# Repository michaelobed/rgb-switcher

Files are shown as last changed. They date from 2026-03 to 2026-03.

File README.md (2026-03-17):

# rgb-switcher

Render of v1.0 main board PCB

## What is it?

An open-source switcher for analogue RGBS and YPbPr video, so you don't have to.

## Why?

My wife and I are slowly amassing some retro gaming consoles which we quite enjoy, and needed a way to connect them all to a modern TV via a [gbs-control](https://github.com/ramapcsx2/gbs-control)-based line doubler. Unfortunately, most solutions for this either don't support RGBS, don't support YPbPr (a must for certain consoles), are SCART-only, don't have many inputs or are ludicrously expensive! Worst of all, they often don't feature remote control of any kind.

Soooo I did what any irritated engineer would do and made my own. 😂

## Overview

### Video switching

The rgb switcher is based around a very old Ben Heck design which uses [74CBT3244](https://www.ti.com/lit/ds/symlink/sn74cbt3244.pdf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) FET bus switches. The idea is simple: an [ATMEGA328PB](https://www.microchip.com/en-us/product/atmega328pb) microcontroller selects which of 8 of these bus switches should be active and switch their inputs through to some commonly connected outputs. The inputs consist of red, green, blue, sync, left audio and right audio. Since some of our consoles use YPbPr video, and because gbs-control-based line doublers have separate inputs for RGB(S) and YPbPr video, there are separate outputs for each, also selected with their own bus switch. A slide switch on the front of the PCB lets you select which video format each input uses, and therefore which output it should be routed to when selected. Bicolour LEDs also indicate which input is active and which format the video is in (red for RGBS, green for YPbPr).

I forgot to mention when writing this that the red, green and blue signals become Pr, Y and Pb respectively when an input is configured to be YPbPr instead of RGBS. There is no sync signal on the YPbPr output. 👍🏾

The input bus switches are selected using [74HC138](https://www.ti.com/product/CD74HC138) inverting line decoders. I could have just used pins on the microcontroller, but these lines go multiple places and I already use a hex inverter for something else on the board and didn't feel like having multiple!

I've used the same 9-pin mini-DIN connector that the Sega Mega Drive II uses, using the exact same pinout. One irritation that I discovered while deciding on this is that the cables I bought for testing (from AliExpress, admittedly) don't output the sync signal on pin 5, but instead output the composite video signal on pin 4! I've therefore added little switches to each input and to the RGBS output that let you choose pin 4 or 5 of the connector, and thus what you'd like to use as a sync signal. Be aware that there isn't any capacity to strip the sync signal from a composite video signal, both because I wasn't designing for that and because gbs-control does it already. If you like, you can add an [LM1881](https://www.ti.com/lit/ds/symlink/lm1881.pdf?ts=1737753066078&ref_url=https%253A%252F%252Fwww.google.com%252F) to the board if that's needed. This _doooes_ also imply that you could use this to switch composite video. Ha!

I got the cables I used for input/output from AliExpress, for example [this one](https://www.aliexpress.com/item/1005005996147435.html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), but the cables typically look like this:

What an I/O cable looks like

You can obtain these by searching for "sega mega drive 2 av cable" and you'll usually find one. You can then put [generic RCA couplers](https://www.aliexpress.com/item/32996572551.html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) on them to turn them into input cables.

### RGB LEDs

I also wanted the consoles to look nice on shelves or some sort of storage system we haven't decided on yet, so why not have the select lines also illuminate strips of 12V RGB LEDs? 🤣
I added some [IRF540](https://www.vishay.com/docs/91021/irf540.pdf) power MOSFETs to help with this. MOSFETs because efficient, power because current through the LEDs does add up!

Since I wanted to make this modular, the LED board now gets its own board as of v1.0 of the project:

Render of v1.0 LED board PCB

The LEDs also fade in/out when changing inputs. Yey! ^-^

### UART

Initially, I was going to build into the board a radio transceiver and build a separate board to use as a remote, partly because it's better than IR and because I had some nRF24L01 modules in my parts bin not really doing anything! It turns out that I hate them, powering them is finicky and I don't want to use an Arduino library, so I provided a generic UART interface instead. That way, I can design a remote of some kind in future (or maybe you, most esteemed reader, are the solution! 😉). I've also left a 5V power output near the UART connector so external remote interfaces can be powered.

I've left some brief documentation in the firmware README. The rgb switcher sends strings whenever the prev/next buttons are pressed and responds to external commands given using simple strings. You can even change the colour associated with an input this way!

Be warned, though, that there is no string sanitisation of any kind, so you can probably crash the microcontroller by being a silly billy with what you send it.

### Power

Finally, there's the power input. Anything that supplies 12V at ≥3A is fine, the high current being to drive the LEDs. Be sure to use a **centre-positive** DC barrel jack with a 5.5mm outer diameter and a 2.5mm inner diameter. I haven't provided any reverse voltage protection because I genuinely forgot. ~~Perhaps a Schottky diode in series with the 12V rail will do the trick.~~

## Final notes

I'm not an expert PCB designer, and this is my first time doing anything with video, but I managed to succesfully test this and get it working! I did make a hilarious number of really dumb mistakes which you can read in the changelog in the hardware README (yes I did eventually rewire the 9-pin mini-DINs by hand to test them). Despite all this, video and audio quality should be good.

If you like this design, you're welcome (and encouraged!) to fork this repo and make one yourself, modify it, sell it, I don't mind!

Happy gaming!

## In future

These are things I should probably have done but haven't had the time to do yet:

- ~~**Make the board smaller**! It would probably have been better to make the switcher with an "LED board" as a module that communicates over the UART, SPI, I2C, etc. Most importantly, it brings cost down further to not make such a large 4-layer PCB, especially if you're not interested in the RGB LED bit.~~
- **Create a reference design for a remote board** that lets you use one of those universal IR TV remotes with it, or maybe even learn codes from an existing IR remote.
- **Create an enclosure**. I'm a CAD noob but it shouldn't be too hard. It could even just be an identically-shaped PCB with some elaborate artwork on it!
- **Give the LED board reverse voltage protection**. This is particularly important for the +12V rail as there's currently nothing stopping a centre-negative DC connection from frying everything. While I suggested a Schottky diode earlier, I'm thinking a P-channel power MOFSET, for voltage drop and power dissipation reasons.

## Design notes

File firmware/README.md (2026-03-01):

# rgb switcher firmware

This firmware was written for the Microchip ATMEGA328PB. It was initially tested on an ATMEGA328P, which should be pin-compatible. Actually, with a little bit of work, this will probably run on anything, so use anything you like if the world one day runs out of those.

## How to build

You will need:
- A text editor. I use [Visual Studio Code](https://code.visualstudio.com) and have added a `.vscode` folder to the repo.
- The AVR GCC toolchain. How you get this depends on your OS, but if you're on macOS like me, I recommend [this repo](https://github.com/osx-cross/homebrew-avr) which contains a guide using a Homebrew-based approach.
- AVRDude. As with AVR GCC, you will need to get this according to your OS's method of doing that. If you've installed Arduino, you likely already have it. If you're on macOS and used the guide from earlier, you can install it by typing `brew install avrdude` in Terminal.

If you happen to be on an arm64 Mac, you should now be able to do either of the following:
- Open `firmware/main_board/src` in Visual Studio code, then run the _Build (Mac)_ task.
- In Terminal, do `cd firmware/main_board` then `../scripts/build_mac.sh`, which achieves the same thing.

This will build a .hex file to `firmware/main_board/bin`, which you can now flash using AVRDude.

If you're not using an arm64 Mac, you will need to change some directories in the `build_mac.sh` script, or create an equivalent for your platform. If you do happen to be on a Windows machine, please feel free to contribute a batch script or equivalent to the repo!

## UART protocol

The UART can receive commands from other devices and respond to them with an acknowledgement. This is useful both for remotely controlling the rgb switcher and for connected devices finding out its latest state (e.g. if the prev/next buttons are pressed). A command-response system has been implemented for controlling the rgb switcher and uses human-readable ASCII characters for everything.

The UART is configured as 8N1, running at 38400 kbaud.

The list of currently available commands is given below:

| Command | Format | Description |
| --- | --- | --- |
| Previous input | `p` | Decrements currently selected input. |
| Next input | `n` | Increments currently selected input. |
| Switch to input | `sN` | Switches to input `N`. |
| No input | `o` | Deselects all inputs. |
| Change input colour | `cNRRGGBB` | Changes the RGB LED colour associated with input `N` to the colour `RRGGBB`, where `RR`, `GG` and `BB` are 8-bit hexadecimal numbers representing the red, green and blue values of the colour. |
| Acknowledgement | `aCP` | Acknowledgement of the command `C` and its parameters `P`. `P` can be any length depending on the command being acknowledged. |
| Hello | `h` | Currently unused, but could be used to detect the presence of other devices. |
| Firmware version | `v` | Queries the switcher for its current version, given as an ASCII string of up to 16 characters. |

All strings sent or received are required to end in a newline (`\n`) character. Windows style `\r\n` endings are fine as the `\r` will just be ignored. As mentioned in the main README, no string sanitisation is performed, and no bounds checking either, so if you supply a malformed string or pass in an out-of-bounds input index...well I'm sure you can handle it! 😅

Feel free to extend this and make cool remotes and interfaces and things!

## EEPROM memory map

| Range | Description |
| --- | --- |
| 0x0000 - 0x000f | No man's land! It's apparently unreliable, so avoid. |
| 0x0010 - 0x0013 | Signature, known value used to verify that data exists. |
| 0x0020 - 0x003f | RGB LED colour data for each input (4 bytes * 8). |

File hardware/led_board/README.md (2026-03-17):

# rgb switcher led board

Here's the KiCad design file for the LED board. As before, third-party libraries are included where necessary, and there's an included BOM in the [KiCAD JLCPCB tools](https://github.com/bouni/kicad-jlcpcb-tools) format.

Bear in mind that you don't absolutely have to use the parts referenced in there if they aren't in stock on LCSC, or if you can source them from elsewhere, or if better/cheaper alternatives will work.

FWIW, here are some alternative links to things you will need. I used AliExpress myself, but these should be equivalent:

- [RGB LED connectors](https://uk.farnell.com/amphenol-anytek/oq04125100j0g/terminal-block-r-a-header-4way/dp/3810285) (Farnell)
- [+5v in/out connector](https://uk.farnell.com/camdenboss/ctb932hd-2/terminal-block-header-2pos-th/dp/2493677) (Farnell)
- [On/off switch](https://www.digikey.co.uk/en/products/detail/e-switch/100SP3T2B4M6RE/378850) (DigiKey)

## changelog

### v1.0

- initial version, based on v0.2 main board design.
- eliminated line decoder and NOT gate so power mosfets are driven directly by mcu gpio.

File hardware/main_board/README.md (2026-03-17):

# rgb switcher main board

Here's the KiCad design file for the main board. I've included all required libraries as a lot of the components I had to find or make from scratch. I've also included a bill of materials (BOM) for reference, which you will need the rather excellent [KiCAD JLCPCB tools](https://github.com/bouni/kicad-jlcpcb-tools) plugin to use. I've done this so that JLCPCB-compatible BOM and CPL files can be directly exported without fuss.

Bear in mind that you don't absolutely have to use the parts referenced in there if they aren't in stock on LCSC, or if you can source them from elsewhere, or if better/cheaper alternatives will work.

FWIW, here are some alternative links to things you will need. I used AliExpress myself, but these should be equivalent:

- [Output indicator LEDs](https://uk.farnell.com/multicomp-pro/mcl056purgw/led-5mm-ac-hi-red-grn/dp/1581207) (Farnell)
- [+5v in/out connector](https://uk.farnell.com/camdenboss/ctb932hd-2/terminal-block-header-2pos-th/dp/2493677) (Farnell)
- [Video input/output connectors](https://www.digikey.co.uk/en/products/detail/kycon-inc/KMDGX-9S-BS-1/10127398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) (DigiKey)

## changelog

### v0.1

- initial version. mistakes were made. 🥲

### v0.2

- corrected reversed pinout of icsp connector.
- corrected reversed pinout of uart connector.
- corrected orientation of prev/next buttons.
- corrected "output on" leds so rgb is red and ypbpr is green.
- corrected stupid pin numbering of mini-din footprint.
- added holes to 9-pin mini-din footprint to prevent ripping connector off board during disconnection.
- moved rgb/ypbpr switches closer to edge for ease of use.
- reduced brightness of "output on" leds.
- permitted switching between pins 4 and 5 of the input/output connectors to support using non-rgbs cables.
- connected PIN_SELEN net to front LED line decoders to allow them to be switched off.

### v1.0

- removed led functionality so it functions only as a video switcher.
- reduced the board dimensions to 135x226mm.
- moved prev/next buttons closer to edge for ease of use.
- migrated bom to [KiCAD JLCPCB tools](https://github.com/bouni/kicad-jlcpcb-tools) plugin format for ease of exporting bom and cpl files.
- lots of routing improvements

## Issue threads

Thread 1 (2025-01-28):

Audio can still distort!

michaelobed, 2025-01-28:
While testing this with a PlayStation 2 playing FIFA Street going through the YPbPr output (a game I deliberately chose because the audio can get loud), I've found the audio still clips. This might be because of the biasing circuit, but I'm not sure.

I've now got some investigative work to do to find out whether the biasing circuitry is even necessary. If the distortion goes away without it, I'll remove it.

If it turns out that removing the biasing circuitry breaks audio, I could simply reduce the gain of the op-amps slightly.

michaelobed, 2025-02-04:
I've done a bit of investigation, and it seems that removing the biasing circuitry seriously breaks audio. In the best case, audio is very distorted and crackly, and in the worst case I get almost no audio, with the occasional crackle making its way through. After biasing the signal, the bus switches will pass audio through cleanly and without issues.

Based on these findings then, I'll play with adding a TL-074-based amplifier at the output with the gain set to <1 to act as attenuation.

michaelobed, 2025-02-06:
I'll need to measure a few things to get an idea of gain, following my comment about how much louder the output is than the input.

Here I've fed a 1kHz sine wave into an input (yellow) and measured the output (blue). This was as high as I could turn up the input before the output became very nonlinear:

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

Past ~900mV pk the output signal experiences nonlinearities.

michaelobed, 2025-02-17:
Attempting to power the op-amps off of 12V was unsuccessful. It's just as distorted as before. I suspect it's because the audio signal is still hitting the 0V rail when biased up to +2V5.

What _was_ successful, though, was removing the biasing circuitry entirely. 😒
I'm annoyed about this because I was convinced that negative voltages would be a problem for the bus switches, but evidently not. I think I'm just going to make that change to the schematic and be done with this. 😂

Closed 2025-02-17.

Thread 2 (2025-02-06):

Add standby feature

michaelobed, 2025-02-06:
It may be desirable to keep the RGB switcher on but not have any outputs enabled. The firmware actually used to work this way, but the way the front LED logic was implemented currently makes it impossible to turn the LEDs off without hardware changes.

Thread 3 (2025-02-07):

Actually remember what the colours were set to

michaelobed, 2025-02-07:
I added code to let people change what RGB LED colour each input is, but no way to remember them! I'm annoyed I over looked it, but it's time to use the AVR EEPROM!

michaelobed, 2025-02-07:
Done! Praise God! 🙌🏾

Closed 2025-02-07.

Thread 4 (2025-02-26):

Change to MIT license

michaelobed, 2025-02-26:
I've not actually open-sourced a project before, but I've realised how restrictive the GNU GPL license can be, in that any derivative but proprietary works must disclose source code.

I've said in the README that I encouraged doing literally whatever one wants with the firmware and hardware designs, and I meant it, so I've created this issue to formally state that I'm switching this repo over to the MIT license, which will allow that.

Closed 2025-02-26.

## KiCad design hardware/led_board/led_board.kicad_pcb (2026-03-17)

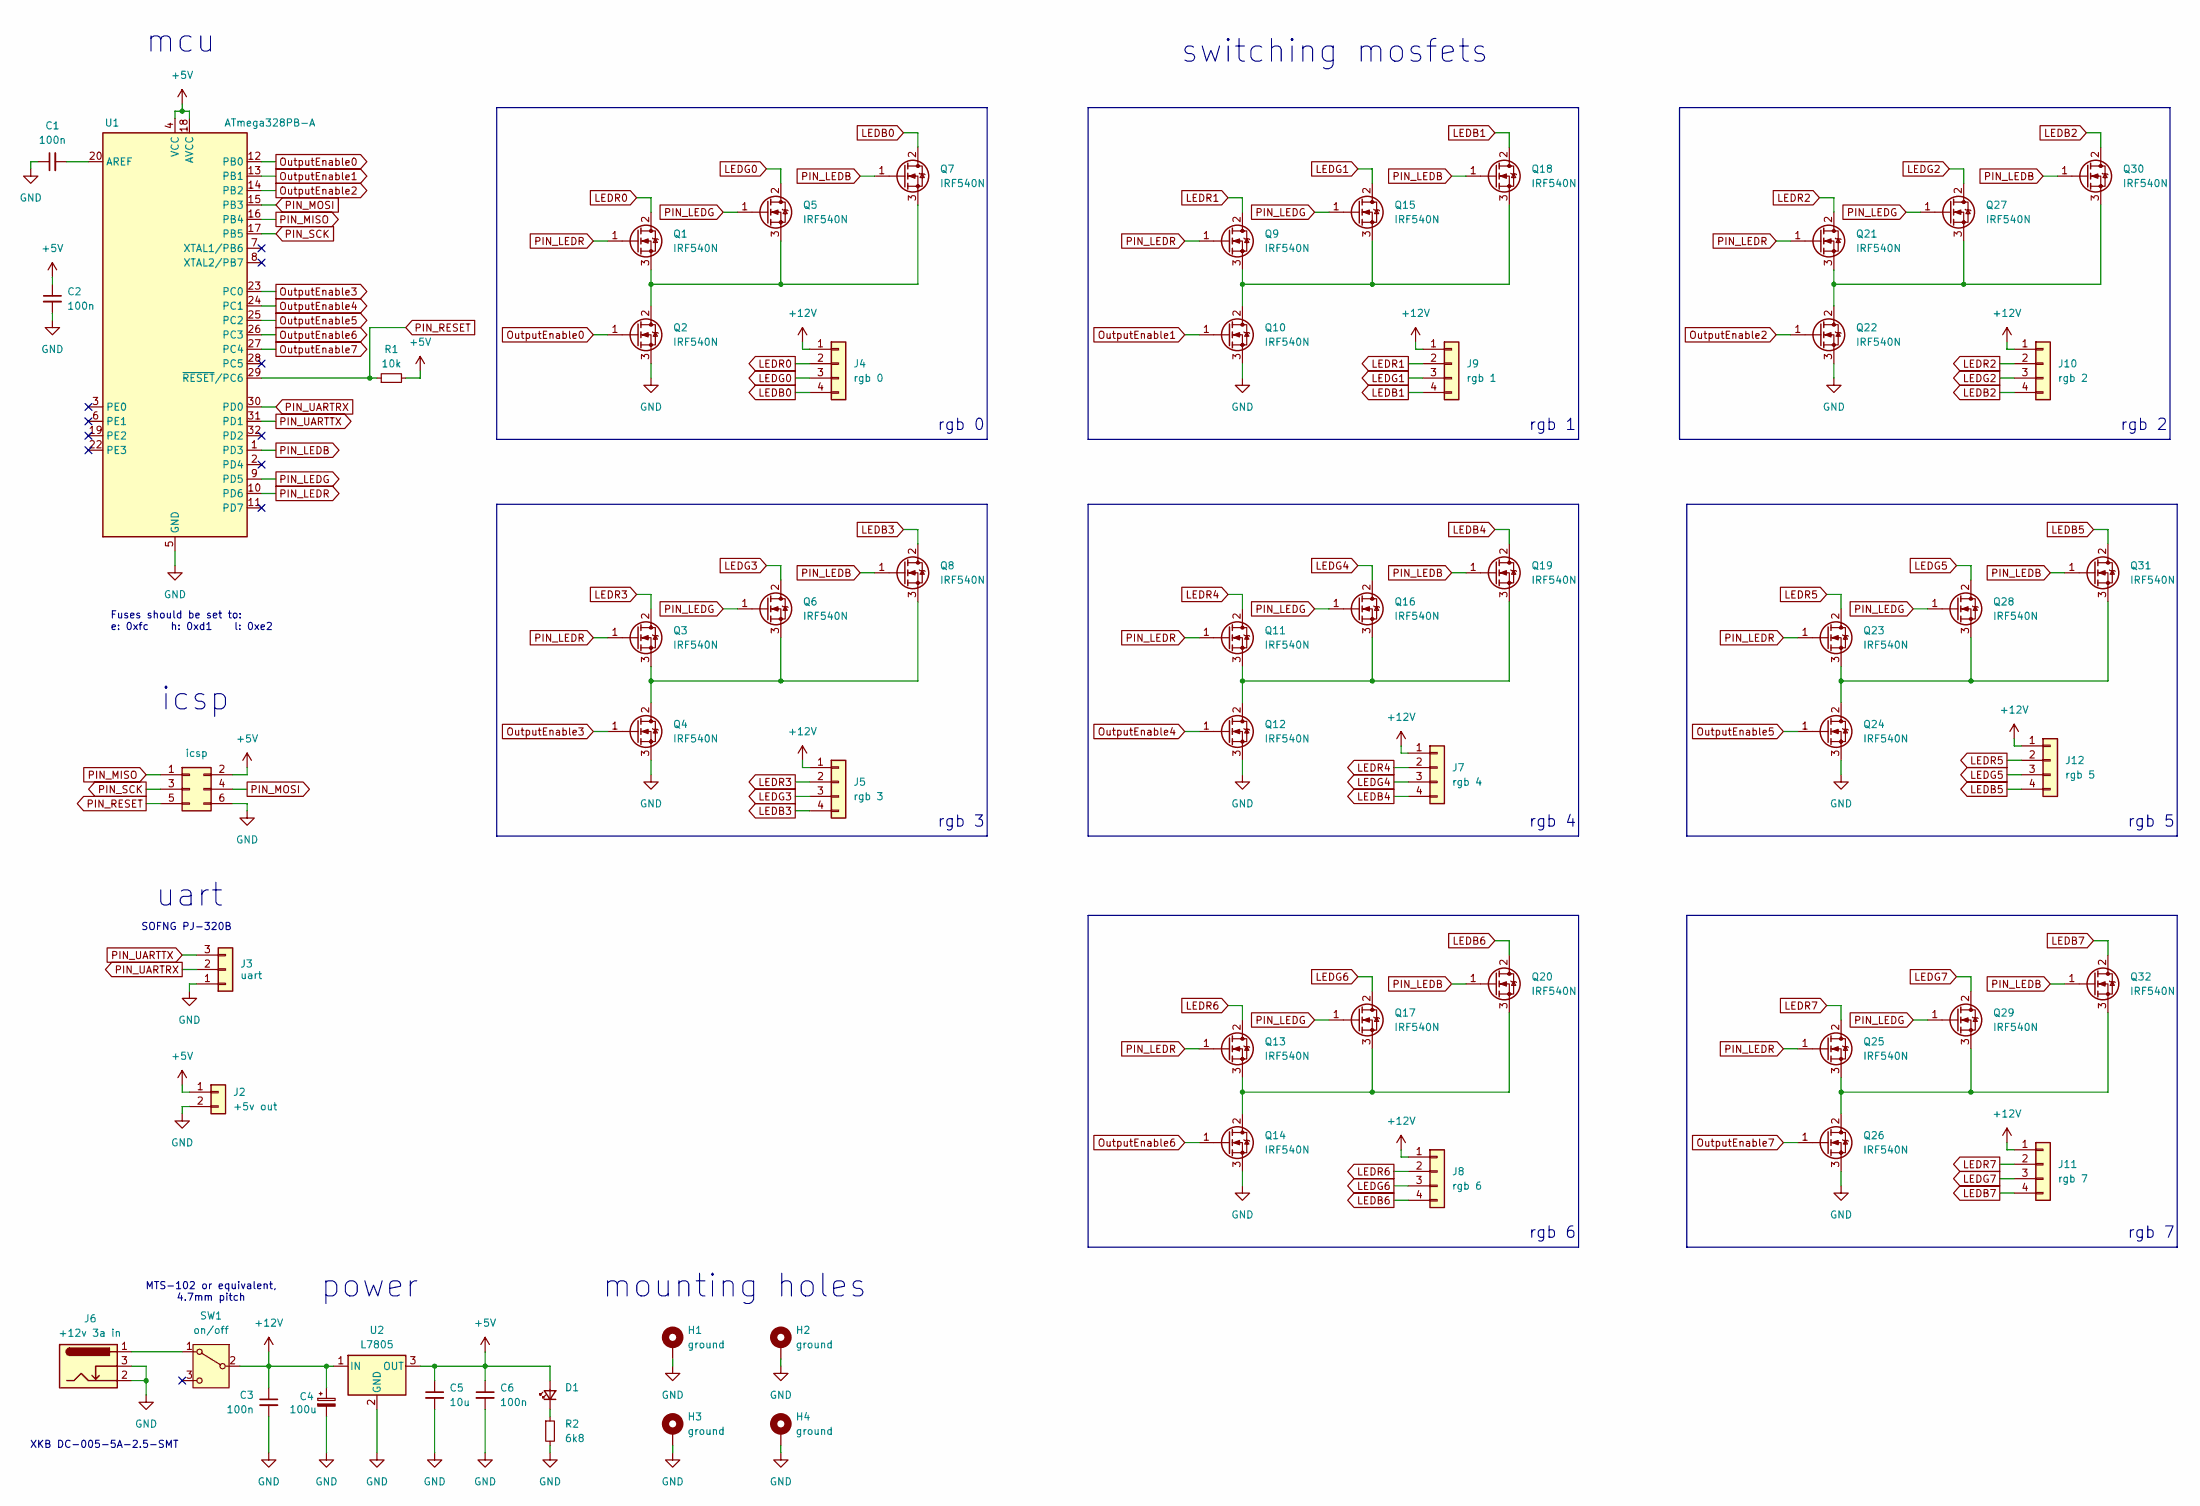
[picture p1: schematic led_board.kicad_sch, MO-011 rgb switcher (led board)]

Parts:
C1, C2, C3, C6: 100n; C_0603_1608Metric
C4: 100u; CP_Elec_6.3x7.7
C5: 10u; C_0603_1608Metric
D1: power; LED_0603_1608Metric
H1, H2, H3, H4: ground; MountingHole_4.3mm_M4_ISO14580_Pad
J1: icsp; PinHeader_2x03_P2.54mm_Vertical
J2: +5v out; PhoenixContact_MC_1,5_2-G-3.5_1x02_P3.50mm_Horizontal
J3: uart; BOOMELE_PJ-320B
J4: rgb 0; PhoenixContact_MC_1,5_4-G-3.5_1x04_P3.50mm_Horizontal
J5: rgb 3; PhoenixContact_MC_1,5_4-G-3.5_1x04_P3.50mm_Horizontal
J6: +12v 3a in; BarrelJack_CLIFF_FC681465S_SMT_Horizontal
J7: rgb 4; PhoenixContact_MC_1,5_4-G-3.5_1x04_P3.50mm_Horizontal
J8: rgb 6; PhoenixContact_MC_1,5_4-G-3.5_1x04_P3.50mm_Horizontal
J9: rgb 1; PhoenixContact_MC_1,5_4-G-3.5_1x04_P3.50mm_Horizontal
J10: rgb 2; PhoenixContact_MC_1,5_4-G-3.5_1x04_P3.50mm_Horizontal
J11: rgb 7; PhoenixContact_MC_1,5_4-G-3.5_1x04_P3.50mm_Horizontal
J12: rgb 5; PhoenixContact_MC_1,5_4-G-3.5_1x04_P3.50mm_Horizontal
Q1, Q2, Q3, Q4, Q5, Q6, Q7, Q8, Q9, Q10, Q11, Q12, Q13, Q14, Q15, Q16, Q17, Q18, Q19, Q20, Q21, Q22, Q23, Q24, Q25, Q26, Q27, Q28, Q29, Q30, Q31, Q32: IRF540N; TO-263-2
R1: 10k; R_0603_1608Metric
R2: 6k8; R_0603_1608Metric
SW1: on/off; SW_Toggle_Blue_wSlots
U1: ATmega328PB-A; TQFP-32_7x7mm_P0.8mm
U2: L7805; TO-263-2

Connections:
+5V: C2.1, C5.1, C6.1, D1.2 (A), J1.2, J2.1, R1.2, U1.4 (VCC), U1.18 (AVCC), U2.3 (OUT)
+12V: C3.1, C4.1, J4.1, J5.1, J7.1, J8.1, J9.1, J10.1, J11.1, J12.1, SW1.2 (B), U2.1 (IN)
GND: C1.1, C2.2, C3.2, C4.2, C5.2, C6.2, H1.1, H2.1, H3.1, H4.1, J1.6, J2.2, J3.1, J6.2, J6.3, Q2.3 (S), Q4.3 (S), Q10.3 (S), Q12.3 (S), Q14.3 (S), Q22.3 (S), Q24.3 (S), Q26.3 (S), R2.2, U1.5 (GND), U1.21 (GND), U2.2 (GND)
LEDB0: J4.4, Q7.2 (D)
LEDB1: J9.4, Q18.2 (D)
LEDB2: J10.4, Q30.2 (D)
LEDB3: J5.4, Q8.2 (D)
LEDB4: J7.4, Q19.2 (D)
LEDB5: J12.4, Q31.2 (D)
LEDB6: J8.4, Q20.2 (D)
LEDB7: J11.4, Q32.2 (D)
LEDG0: J4.3, Q5.2 (D)
LEDG1: J9.3, Q15.2 (D)
LEDG2: J10.3, Q27.2 (D)
LEDG3: J5.3, Q6.2 (D)
LEDG4: J7.3, Q16.2 (D)
LEDG5: J12.3, Q28.2 (D)
LEDG6: J8.3, Q17.2 (D)
LEDG7: J11.3, Q29.2 (D)
LEDR0: J4.2, Q1.2 (D)
LEDR1: J9.2, Q9.2 (D)
LEDR2: J10.2, Q21.2 (D)
LEDR3: J5.2, Q3.2 (D)
LEDR4: J7.2, Q11.2 (D)
LEDR5: J12.2, Q23.2 (D)
LEDR6: J8.2, Q13.2 (D)
LEDR7: J11.2, Q25.2 (D)
unnamed: D1.1 (K), R2.1
unnamed: Q1.3 (S), Q2.2 (D), Q5.3 (S), Q7.3 (S)
unnamed: Q3.3 (S), Q4.2 (D), Q6.3 (S), Q8.3 (S)
unnamed: Q9.3 (S), Q10.2 (D), Q15.3 (S), Q18.3 (S)
unnamed: Q11.3 (S), Q12.2 (D), Q16.3 (S), Q19.3 (S)
unnamed: Q13.3 (S), Q14.2 (D), Q17.3 (S), Q20.3 (S)
unnamed: Q21.3 (S), Q22.2 (D), Q27.3 (S), Q30.3 (S)
unnamed: Q23.3 (S), Q24.2 (D), Q28.3 (S), Q31.3 (S)
unnamed: Q25.3 (S), Q26.2 (D), Q29.3 (S), Q32.3 (S)
unnamed: J6.1, SW1.1 (A)
unnamed: C1.2, U1.20 (AREF)
OutputEnable0: Q2.1 (G), U1.12 (PB0)
OutputEnable1: Q10.1 (G), U1.13 (PB1)
OutputEnable2: Q22.1 (G), U1.14 (PB2)
OutputEnable3: Q4.1 (G), U1.23 (PC0)
OutputEnable4: Q12.1 (G), U1.24 (PC1)
OutputEnable5: Q24.1 (G), U1.25 (PC2)
OutputEnable6: Q14.1 (G), U1.26 (PC3)
OutputEnable7: Q26.1 (G), U1.27 (PC4)
PIN_LEDB: Q7.1 (G), Q8.1 (G), Q18.1 (G), Q19.1 (G), Q20.1 (G), Q30.1 (G), Q31.1 (G), Q32.1 (G), U1.1 (PD3)
PIN_LEDG: Q5.1 (G), Q6.1 (G), Q15.1 (G), Q16.1 (G), Q17.1 (G), Q27.1 (G), Q28.1 (G), Q29.1 (G), U1.9 (PD5)
PIN_LEDR: Q1.1 (G), Q3.1 (G), Q9.1 (G), Q11.1 (G), Q13.1 (G), Q21.1 (G), Q23.1 (G), Q25.1 (G), U1.10 (PD6)
PIN_MISO: J1.1, U1.16 (PB4)
PIN_MOSI: J1.4, U1.15 (PB3)
PIN_RESET: J1.5, R1.1, U1.29 (~RESET/PC6)
PIN_SCK: J1.3, U1.17 (PB5)
PIN_UARTRX: J3.2, U1.30 (PD0)
PIN_UARTTX: J3.3, U1.31 (PD1)

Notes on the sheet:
power
rgb 3
rgb 5
SOFNG PJ-320B
rgb 4
rgb 1
XKB DC-005-5A-2.5-SMT
mounting holes
rgb 6
rgb 2
mcu
Fuses should be set to: e: 0xfc h: 0xd1 l: 0xe2
MTS-102 or equivalent, 4.7mm pitch
uart
switching mosfets
icsp
rgb 7
rgb 0

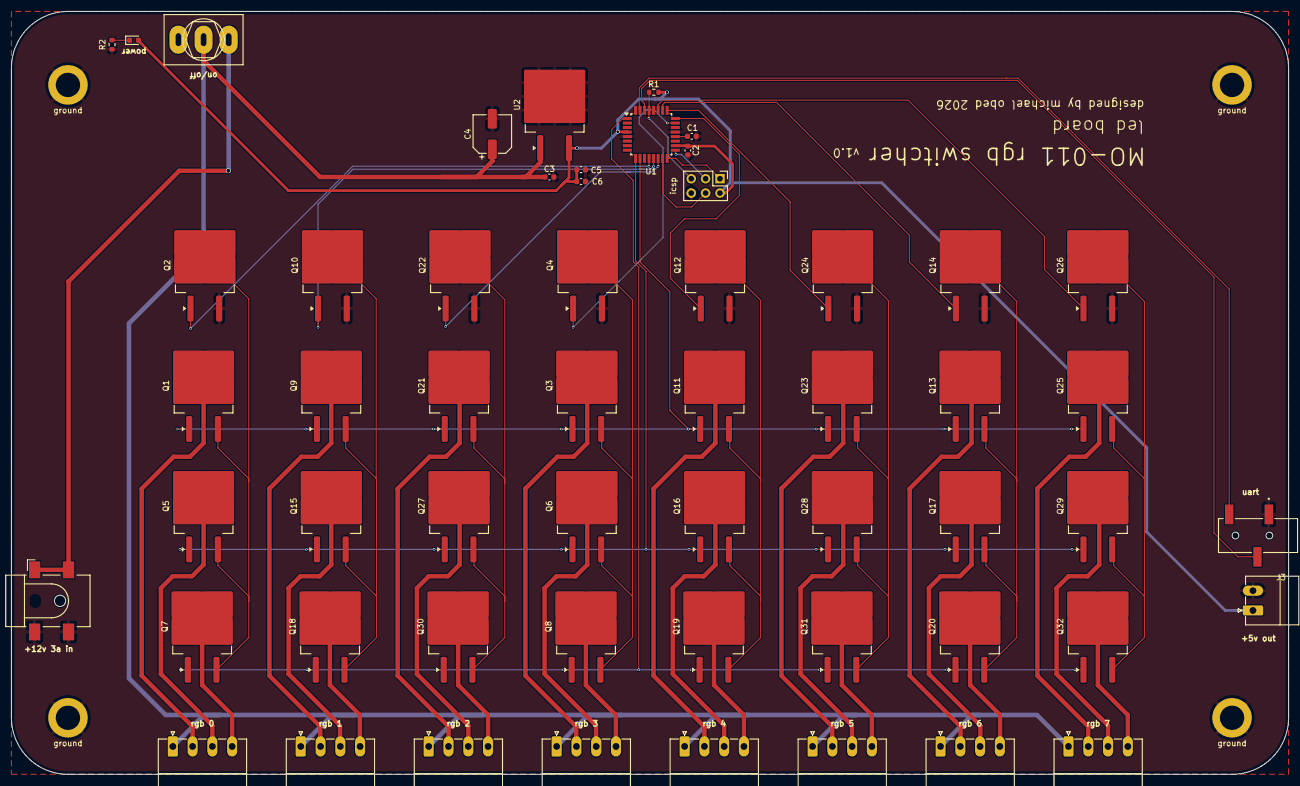
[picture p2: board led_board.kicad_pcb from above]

Board: 2 copper layers, 226.0 x 135.0 mm, 60 parts (0 on the bottom side), 55 nets.

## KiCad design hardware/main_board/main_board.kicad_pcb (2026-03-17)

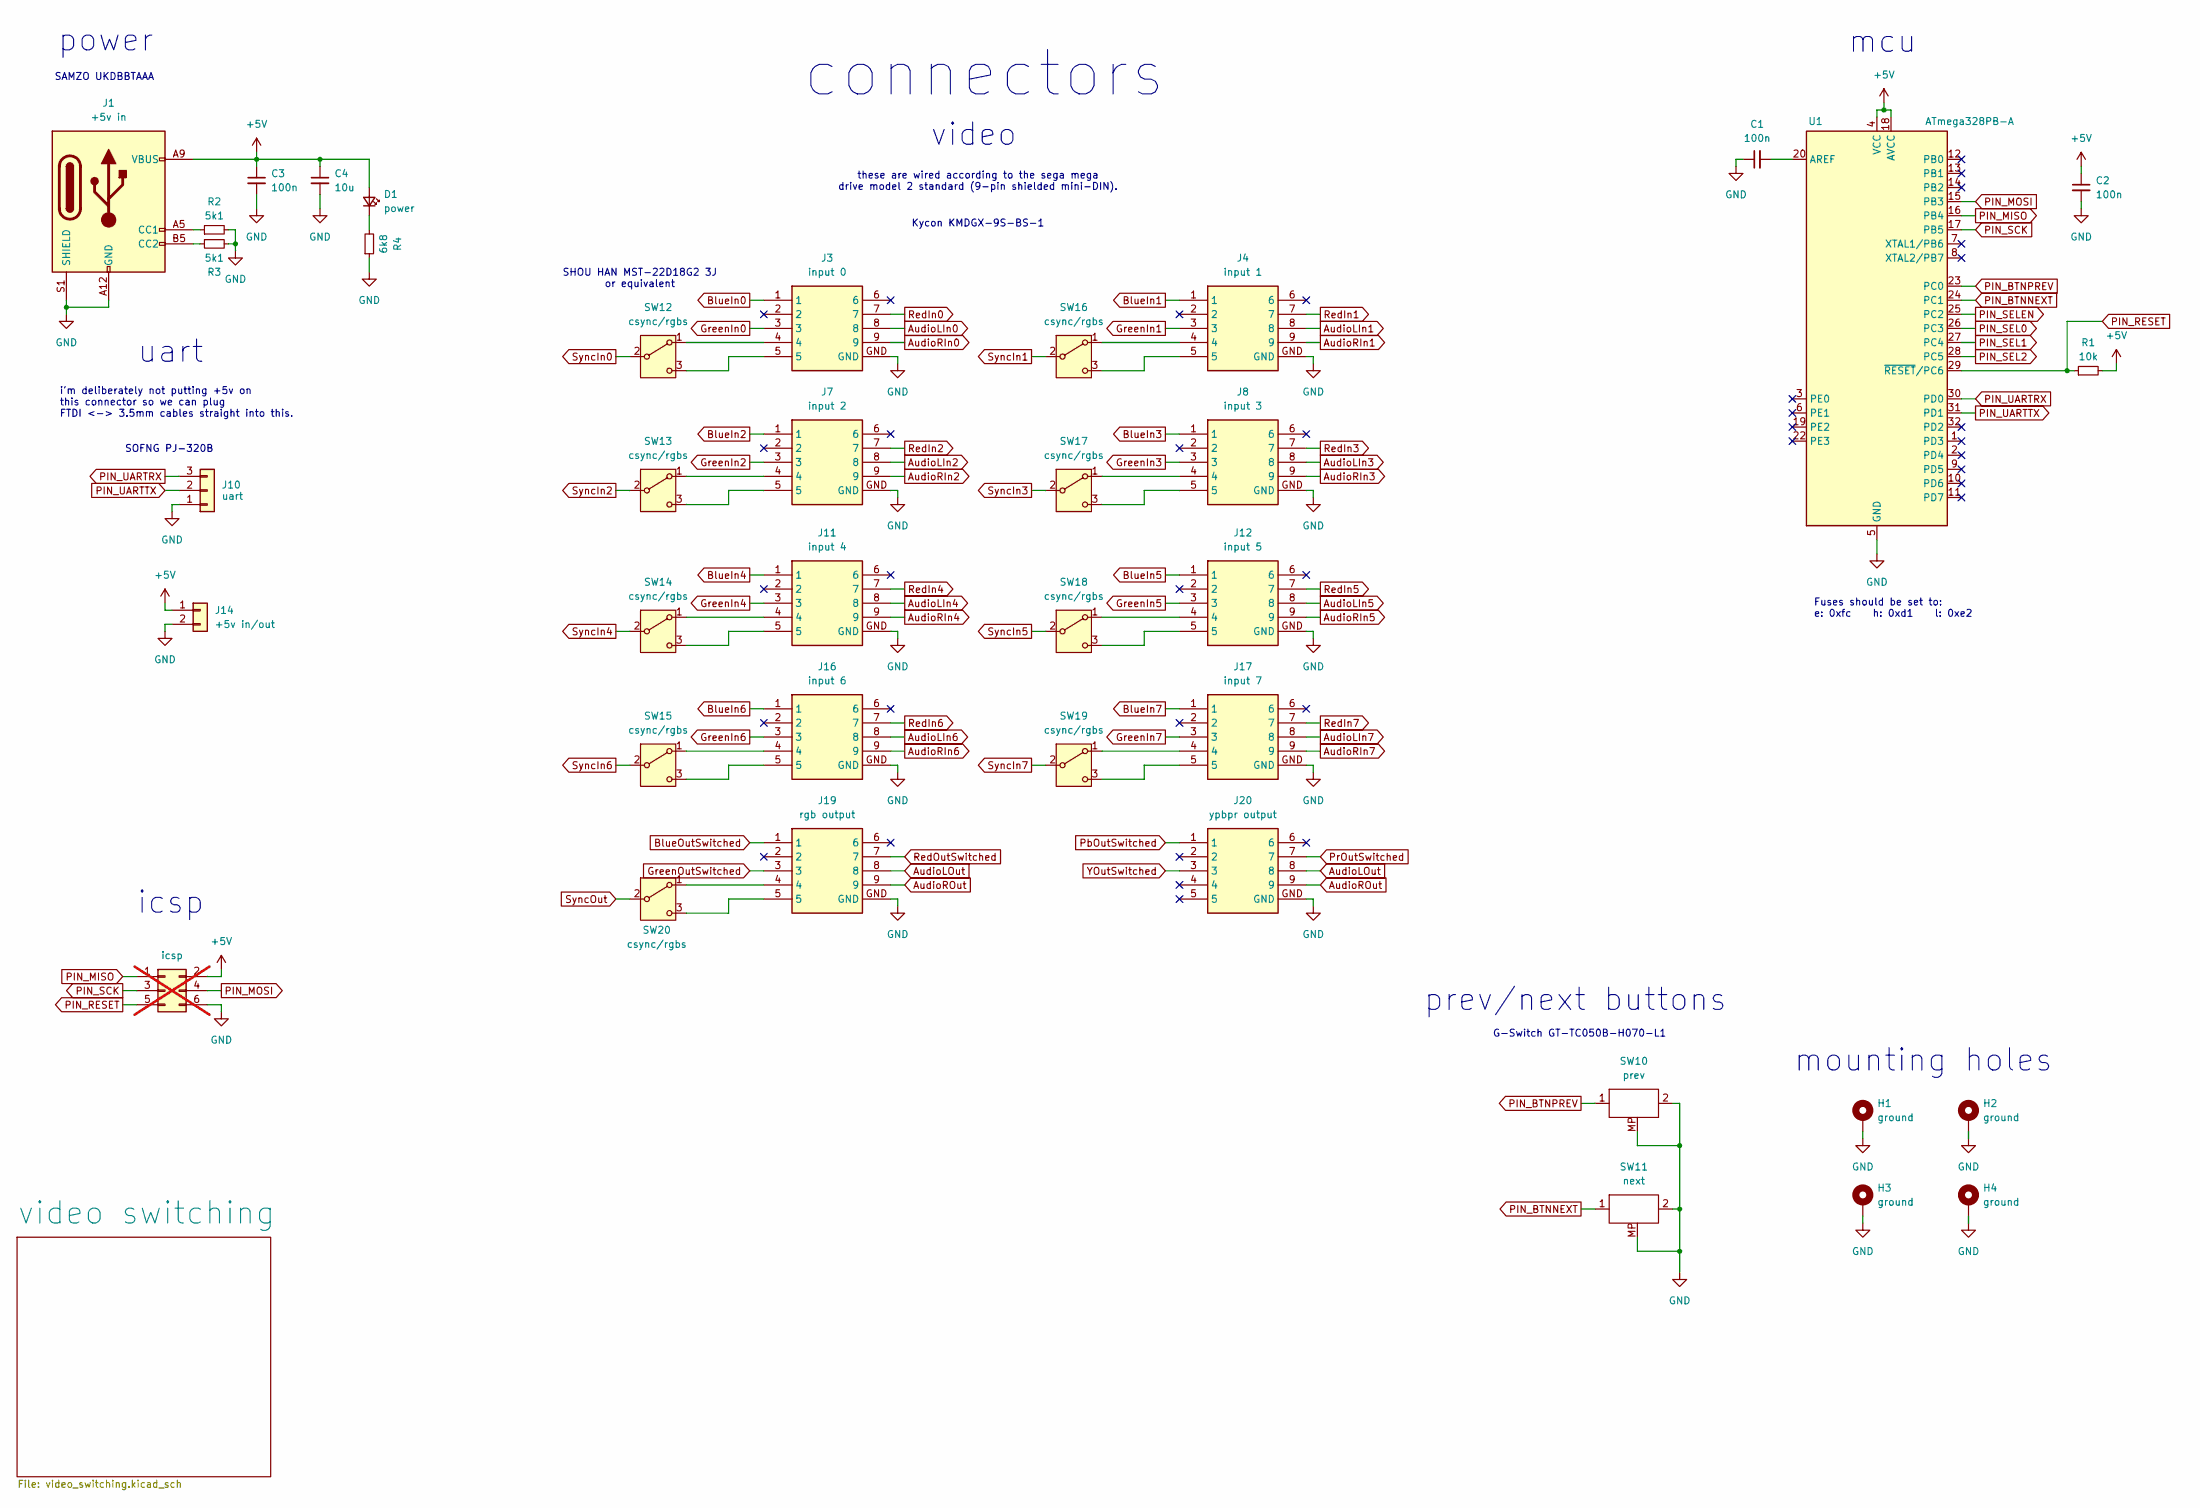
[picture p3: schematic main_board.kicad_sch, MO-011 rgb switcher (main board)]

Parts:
C1, C2, C3: 100n; C_0603_1608Metric
C4: 10u; C_0603_1608Metric
D1: power; LED_0603_1608Metric
H1, H2, H3, H4: ground; MountingHole_4.3mm_M4_ISO14580_Pad
J1: +5v in; USB_C_Receptacle_HRO_TYPE-C-31-M-17
J3: input 0; KMDGX9SN; Mouser Part Number 806-KMDGX-9S-N
J4: input 1; KMDGX9SN; Mouser Part Number 806-KMDGX-9S-N
J5: icsp; PinHeader_2x03_P2.54mm_Vertical; not fitted
J7: input 2; KMDGX9SN; Mouser Part Number 806-KMDGX-9S-N
J8: input 3; KMDGX9SN; Mouser Part Number 806-KMDGX-9S-N
J10: uart; BOOMELE_PJ-320B
J11: input 4; KMDGX9SN; Mouser Part Number 806-KMDGX-9S-N
J12: input 5; KMDGX9SN; Mouser Part Number 806-KMDGX-9S-N
J14: +5v in/out; PhoenixContact_MC_1,5_2-G-3.5_1x02_P3.50mm_Horizontal
J16: input 6; KMDGX9SN; Mouser Part Number 806-KMDGX-9S-N
J17: input 7; KMDGX9SN; Mouser Part Number 806-KMDGX-9S-N
J19: rgb output; KMDGX9SN; Mouser Part Number 806-KMDGX-9S-N
J20: ypbpr output; KMDGX9SN; Mouser Part Number 806-KMDGX-9S-N
R1: 10k; R_0603_1608Metric
R2, R3: 5k1; R_0603_1608Metric
R4: 6k8; R_0603_1608Metric
SW10: prev; GT-TC060B
SW11: next; GT-TC060B
SW12, SW13, SW14, SW15, SW16, SW17, SW18, SW19, SW20: csync/rgbs; SW_JS102011JCQN
U1: ATmega328PB-A; TQFP-32_7x7mm_P0.8mm

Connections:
+5V: C2.1, C3.1, C4.1, D1.2 (A), J1.A9 (VBUS), J1.B9 (VBUS), J5.2, J14.1, R1.2, U1.4 (VCC), U1.18 (AVCC); also elsewhere on the board
AudioLIn0: J3.8; also elsewhere on the board
AudioLIn1: J4.8; also elsewhere on the board
AudioLIn2: J7.8; also elsewhere on the board
AudioLIn3: J8.8; also elsewhere on the board
AudioLIn4: J11.8; also elsewhere on the board
AudioLIn5: J12.8; also elsewhere on the board
AudioLIn6: J16.8; also elsewhere on the board
AudioLIn7: J17.8; also elsewhere on the board
AudioLOut: J19.8, J20.8; also elsewhere on the board
AudioRIn0: J3.9; also elsewhere on the board
AudioRIn1: J4.9; also elsewhere on the board
AudioRIn2: J7.9; also elsewhere on the board
AudioRIn3: J8.9; also elsewhere on the board
AudioRIn4: J11.9; also elsewhere on the board
AudioRIn5: J12.9; also elsewhere on the board
AudioRIn6: J16.9; also elsewhere on the board
AudioRIn7: J17.9; also elsewhere on the board
AudioROut: J19.9, J20.9; also elsewhere on the board
BlueIn0: J3.1; also elsewhere on the board
BlueIn1: J4.1; also elsewhere on the board
BlueIn2: J7.1; also elsewhere on the board
BlueIn3: J8.1; also elsewhere on the board
BlueIn4: J11.1; also elsewhere on the board
BlueIn5: J12.1; also elsewhere on the board
BlueIn6: J16.1; also elsewhere on the board
BlueIn7: J17.1; also elsewhere on the board
BlueOutSwitched: J19.1; also elsewhere on the board
GND: C1.1, C2.2, C3.2, C4.2, H1.1, H2.1, H3.1, H4.1, J1.A12 (GND), J1.B12 (GND), J1.S1 (SHIELD), J3.GND, J4.GND, J5.6, J7.GND, J8.GND, J10.1, J11.GND, J12.GND, J14.2, J16.GND, J17.GND, J19.GND, J20.GND, R2.2, R3.2, R4.1, SW10.2, SW10.MP, SW11.2, SW11.MP, U1.5 (GND), U1.21 (GND); also elsewhere on the board
GreenIn0: J3.3; also elsewhere on the board
GreenIn1: J4.3; also elsewhere on the board
GreenIn2: J7.3; also elsewhere on the board
GreenIn3: J8.3; also elsewhere on the board
GreenIn4: J11.3; also elsewhere on the board
GreenIn5: J12.3; also elsewhere on the board
GreenIn6: J16.3; also elsewhere on the board
GreenIn7: J17.3; also elsewhere on the board
GreenOutSwitched: J19.3; also elsewhere on the board
unnamed: D1.1 (K), R4.2
unnamed: J1.A5 (CC1), R2.1
unnamed: J1.B5 (CC2), R3.1
unnamed: J3.4, SW12.1 (A)
unnamed: J3.5, SW12.3 (C)
unnamed: J7.4, SW13.1 (A)
unnamed: J7.5, SW13.3 (C)
unnamed: J11.4, SW14.1 (A)
unnamed: J11.5, SW14.3 (C)
unnamed: J16.4, SW15.1 (A)
unnamed: J16.5, SW15.3 (C)
unnamed: J4.4, SW16.1 (A)
unnamed: J4.5, SW16.3 (C)
unnamed: J8.4, SW17.1 (A)
unnamed: J8.5, SW17.3 (C)
unnamed: J12.4, SW18.1 (A)
unnamed: J12.5, SW18.3 (C)
unnamed: J17.4, SW19.1 (A)
unnamed: J17.5, SW19.3 (C)
unnamed: J19.4, SW20.1 (A)
unnamed: J19.5, SW20.3 (C)
unnamed: C1.2, U1.20 (AREF)
PIN_BTNNEXT: SW11.1, U1.24 (PC1)
PIN_BTNPREV: SW10.1, U1.23 (PC0)
PIN_MISO: J5.1, U1.16 (PB4)
PIN_MOSI: J5.4, U1.15 (PB3)
PIN_RESET: J5.5, R1.1, U1.29 (~RESET/PC6)
PIN_SCK: J5.3, U1.17 (PB5)
PIN_SEL0: U1.26 (PC3); also elsewhere on the board
PIN_SEL1: U1.27 (PC4); also elsewhere on the board
PIN_SEL2: U1.28 (PC5); also elsewhere on the board
PIN_SELEN: U1.25 (PC2); also elsewhere on the board
PIN_UARTRX: J10.3, U1.30 (PD0)
PIN_UARTTX: J10.2, U1.31 (PD1)
PbOutSwitched: J20.1; also elsewhere on the board
PrOutSwitched: J20.7; also elsewhere on the board
RedIn0: J3.7; also elsewhere on the board
RedIn1: J4.7; also elsewhere on the board
RedIn2: J7.7; also elsewhere on the board
RedIn3: J8.7; also elsewhere on the board
RedIn4: J11.7; also elsewhere on the board
RedIn5: J12.7; also elsewhere on the board
RedIn6: J16.7; also elsewhere on the board
RedIn7: J17.7; also elsewhere on the board
RedOutSwitched: J19.7; also elsewhere on the board
SyncIn0: SW12.2 (B); also elsewhere on the board
SyncIn1: SW16.2 (B); also elsewhere on the board
SyncIn2: SW13.2 (B); also elsewhere on the board
SyncIn3: SW17.2 (B); also elsewhere on the board
SyncIn4: SW14.2 (B); also elsewhere on the board
SyncIn5: SW18.2 (B); also elsewhere on the board
SyncIn6: SW15.2 (B); also elsewhere on the board
SyncIn7: SW19.2 (B); also elsewhere on the board
SyncOut: SW20.2 (B); also elsewhere on the board
YOutSwitched: J20.3; also elsewhere on the board

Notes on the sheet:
uart
SAMZO UKDBBTAAA
these are wired according to the sega mega drive model 2 standard (9-pin shielded mini-DIN).
i'm deliberately not putting +5v on this connector so we can plug FTDI <-> 3.5mm cables straight into this.
Fuses should be set to: e: 0xfc h: 0xd1 l: 0xe2
icsp
SHOU HAN MST-22D18G2 3J or equivalent
power
G-Switch GT-TC050B-H070-L1
prev/next buttons
mcu
connectors
Kycon KMDGX-9S-BS-1
SOFNG PJ-320B
video
mounting holes

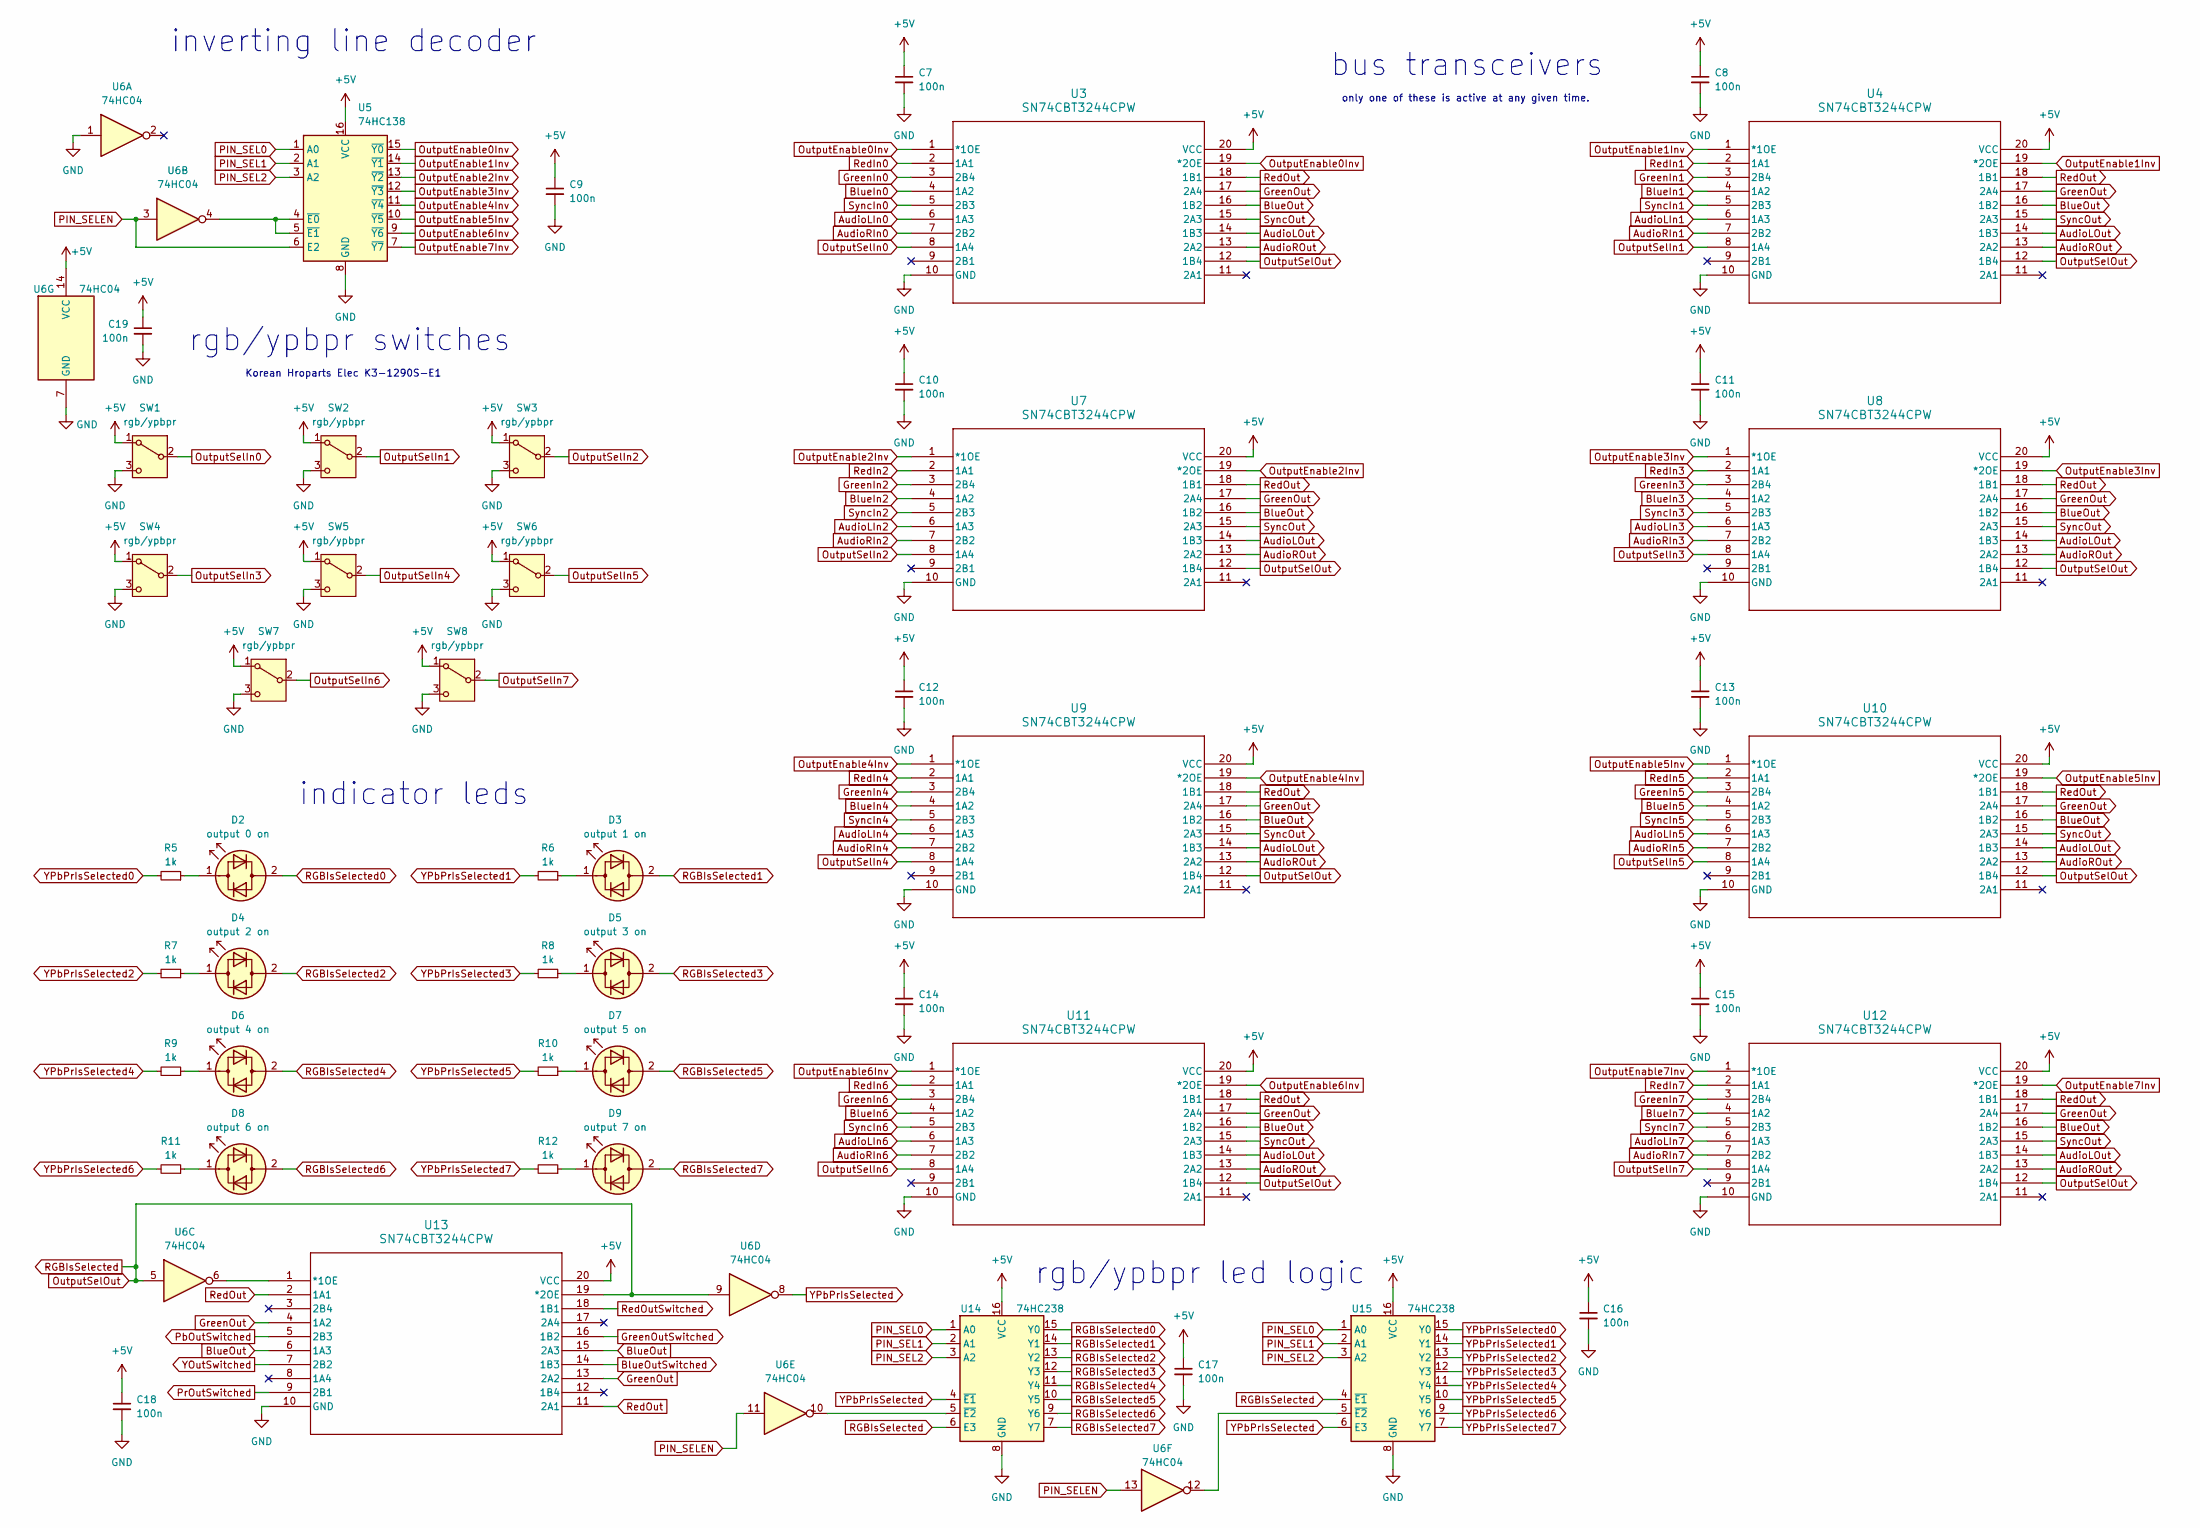
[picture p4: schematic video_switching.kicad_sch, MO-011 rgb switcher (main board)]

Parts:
C7, C8, C9, C10, C11, C12, C13, C14, C15, C16, C17, C18, C19: 100n; C_0603_1608Metric
D2: output 0 on; LED_D5.0mm
D3: output 1 on; LED_D5.0mm
D4: output 2 on; LED_D5.0mm
D5: output 3 on; LED_D5.0mm
D6: output 4 on; LED_D5.0mm
D7: output 5 on; LED_D5.0mm
D8: output 6 on; LED_D5.0mm
D9: output 7 on; LED_D5.0mm
R5, R6, R7, R8, R9, R10, R11, R12: 1k; R_0603_1608Metric
SW1, SW2, SW3, SW4, SW5, SW6, SW7, SW8: rgb/ypbpr; SW_SPDT_PCM12
U3, U4, U7, U8, U9, U10, U11, U12, U13: SN74CBT3244CPW; SOIC-20W_7.5x12.8mm_P1.27mm
U5: 74HC138; SOIC-16_3.9x9.9mm_P1.27mm
U6: 74HC04; SOIC-14_3.9x8.7mm_P1.27mm
U14, U15: 74HC238; SOIC-16_3.9x9.9mm_P1.27mm

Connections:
+5V: C7.1, C8.1, C9.1, C10.1, C11.1, C12.1, C13.1, C14.1, C15.1, C16.1, C17.1, C18.1, C19.1, SW1.1 (A), SW2.1 (A), SW3.1 (A), SW4.1 (A), SW5.1 (A), SW6.1 (A), SW7.1 (A), SW8.1 (A), U3.20 (VCC), U4.20 (VCC), U5.16 (VCC), U6.14 (VCC), U7.20 (VCC), U8.20 (VCC), U9.20 (VCC), U10.20 (VCC), U11.20 (VCC), U12.20 (VCC), U13.20 (VCC), U14.16 (VCC), U15.16 (VCC); also elsewhere on the board
AudioLIn0: U3.6 (1A3); also elsewhere on the board
AudioLIn1: U4.6 (1A3); also elsewhere on the board
AudioLIn2: U7.6 (1A3); also elsewhere on the board
AudioLIn3: U8.6 (1A3); also elsewhere on the board
AudioLIn4: U9.6 (1A3); also elsewhere on the board
AudioLIn5: U10.6 (1A3); also elsewhere on the board
AudioLIn6: U11.6 (1A3); also elsewhere on the board
AudioLIn7: U12.6 (1A3); also elsewhere on the board
AudioLOut: U3.14 (1B3), U4.14 (1B3), U7.14 (1B3), U8.14 (1B3), U9.14 (1B3), U10.14 (1B3), U11.14 (1B3), U12.14 (1B3); also elsewhere on the board
AudioRIn0: U3.7 (2B2); also elsewhere on the board
AudioRIn1: U4.7 (2B2); also elsewhere on the board
AudioRIn2: U7.7 (2B2); also elsewhere on the board
AudioRIn3: U8.7 (2B2); also elsewhere on the board
AudioRIn4: U9.7 (2B2); also elsewhere on the board
AudioRIn5: U10.7 (2B2); also elsewhere on the board
AudioRIn6: U11.7 (2B2); also elsewhere on the board
AudioRIn7: U12.7 (2B2); also elsewhere on the board
AudioROut: U3.13 (2A2), U4.13 (2A2), U7.13 (2A2), U8.13 (2A2), U9.13 (2A2), U10.13 (2A2), U11.13 (2A2), U12.13 (2A2); also elsewhere on the board
BlueIn0: U3.4 (1A2); also elsewhere on the board
BlueIn1: U4.4 (1A2); also elsewhere on the board
BlueIn2: U7.4 (1A2); also elsewhere on the board
BlueIn3: U8.4 (1A2); also elsewhere on the board
BlueIn4: U9.4 (1A2); also elsewhere on the board
BlueIn5: U10.4 (1A2); also elsewhere on the board
BlueIn6: U11.4 (1A2); also elsewhere on the board
BlueIn7: U12.4 (1A2); also elsewhere on the board
BlueOut: U3.16 (1B2), U4.16 (1B2), U7.16 (1B2), U8.16 (1B2), U9.16 (1B2), U10.16 (1B2), U11.16 (1B2), U12.16 (1B2), U13.6 (1A3), U13.15 (2A3)
BlueOutSwitched: U13.14 (1B3); also elsewhere on the board
GND: C7.2, C8.2, C9.2, C10.2, C11.2, C12.2, C13.2, C14.2, C15.2, C16.2, C17.2, C18.2, C19.2, SW1.3 (C), SW2.3 (C), SW3.3 (C), SW4.3 (C), SW5.3 (C), SW6.3 (C), SW7.3 (C), SW8.3 (C), U3.10 (GND), U4.10 (GND), U5.8 (GND), U6.1, U6.7 (GND), U7.10 (GND), U8.10 (GND), U9.10 (GND), U10.10 (GND), U11.10 (GND), U12.10 (GND), U13.10 (GND), U14.8 (GND), U15.8 (GND); also elsewhere on the board
GreenIn0: U3.3 (2B4); also elsewhere on the board
GreenIn1: U4.3 (2B4); also elsewhere on the board
GreenIn2: U7.3 (2B4); also elsewhere on the board
GreenIn3: U8.3 (2B4); also elsewhere on the board
GreenIn4: U9.3 (2B4); also elsewhere on the board
GreenIn5: U10.3 (2B4); also elsewhere on the board
GreenIn6: U11.3 (2B4); also elsewhere on the board
GreenIn7: U12.3 (2B4); also elsewhere on the board
GreenOut: U3.17 (2A4), U4.17 (2A4), U7.17 (2A4), U8.17 (2A4), U9.17 (2A4), U10.17 (2A4), U11.17 (2A4), U12.17 (2A4), U13.4 (1A2), U13.13 (2A2)
GreenOutSwitched: U13.16 (1B2); also elsewhere on the board
unnamed: D2.1 (KA), R5.1
unnamed: D3.1 (KA), R6.1
unnamed: D4.1 (KA), R7.1
unnamed: D5.1 (KA), R8.1
unnamed: D6.1 (KA), R9.1
unnamed: D7.1 (KA), R10.1
unnamed: D8.1 (KA), R11.1
unnamed: D9.1 (KA), R12.1
unnamed: U5.4 (~E0), U5.5 (~E1), U6.4
unnamed: U6.6, U13.1 (*1OE)
unnamed: U6.10, U14.5 (~E2)
unnamed: U6.12, U15.5 (~E2)
OutputEnable0Inv: U3.1 (*1OE), U3.19 (*2OE), U5.15 (~Y0)
OutputEnable1Inv: U4.1 (*1OE), U4.19 (*2OE), U5.14 (~Y1)
OutputEnable2Inv: U5.13 (~Y2), U7.1 (*1OE), U7.19 (*2OE)
OutputEnable3Inv: U5.12 (~Y3), U8.1 (*1OE), U8.19 (*2OE)
OutputEnable4Inv: U5.11 (~Y4), U9.1 (*1OE), U9.19 (*2OE)
OutputEnable5Inv: U5.10 (~Y5), U10.1 (*1OE), U10.19 (*2OE)
OutputEnable6Inv: U5.9 (~Y6), U11.1 (*1OE), U11.19 (*2OE)
OutputEnable7Inv: U5.7 (~Y7), U12.1 (*1OE), U12.19 (*2OE)
OutputSelIn0: SW1.2 (B), U3.8 (1A4)
OutputSelIn1: SW2.2 (B), U4.8 (1A4)
OutputSelIn2: SW3.2 (B), U7.8 (1A4)
OutputSelIn3: SW4.2 (B), U8.8 (1A4)
OutputSelIn4: SW5.2 (B), U9.8 (1A4)
OutputSelIn5: SW6.2 (B), U10.8 (1A4)
OutputSelIn6: SW7.2 (B), U11.8 (1A4)
OutputSelIn7: SW8.2 (B), U12.8 (1A4)
OutputSelOut: U3.12 (1B4), U4.12 (1B4), U6.5, U6.9, U7.12 (1B4), U8.12 (1B4), U9.12 (1B4), U10.12 (1B4), U11.12 (1B4), U12.12 (1B4), U13.19 (*2OE), U14.6 (E3), U15.4 (~E1)
PIN_SEL0: U5.1 (A0), U14.1 (A0), U15.1 (A0); also elsewhere on the board
PIN_SEL1: U5.2 (A1), U14.2 (A1), U15.2 (A1); also elsewhere on the board
PIN_SEL2: U5.3 (A2), U14.3 (A2), U15.3 (A2); also elsewhere on the board
PIN_SELEN: U5.6 (E2), U6.3, U6.11, U6.13; also elsewhere on the board
PbOutSwitched: U13.5 (2B3); also elsewhere on the board
PrOutSwitched: U13.9 (2B1); also elsewhere on the board
RGBIsSelected0: D2.2 (AK), U14.15 (Y0)
RGBIsSelected1: D3.2 (AK), U14.14 (Y1)
RGBIsSelected2: D4.2 (AK), U14.13 (Y2)
RGBIsSelected3: D5.2 (AK), U14.12 (Y3)
RGBIsSelected4: D6.2 (AK), U14.11 (Y4)
RGBIsSelected5: D7.2 (AK), U14.10 (Y5)
RGBIsSelected6: D8.2 (AK), U14.9 (Y6)
RGBIsSelected7: D9.2 (AK), U14.7 (Y7)
RedIn0: U3.2 (1A1); also elsewhere on the board
RedIn1: U4.2 (1A1); also elsewhere on the board
RedIn2: U7.2 (1A1); also elsewhere on the board
RedIn3: U8.2 (1A1); also elsewhere on the board
RedIn4: U9.2 (1A1); also elsewhere on the board
RedIn5: U10.2 (1A1); also elsewhere on the board
RedIn6: U11.2 (1A1); also elsewhere on the board
RedIn7: U12.2 (1A1); also elsewhere on the board
RedOut: U3.18 (1B1), U4.18 (1B1), U7.18 (1B1), U8.18 (1B1), U9.18 (1B1), U10.18 (1B1), U11.18 (1B1), U12.18 (1B1), U13.2 (1A1), U13.11 (2A1)
RedOutSwitched: U13.18 (1B1); also elsewhere on the board
SyncIn0: U3.5 (2B3); also elsewhere on the board
SyncIn1: U4.5 (2B3); also elsewhere on the board
SyncIn2: U7.5 (2B3); also elsewhere on the board
SyncIn3: U8.5 (2B3); also elsewhere on the board
SyncIn4: U9.5 (2B3); also elsewhere on the board
SyncIn5: U10.5 (2B3); also elsewhere on the board
SyncIn6: U11.5 (2B3); also elsewhere on the board
SyncIn7: U12.5 (2B3); also elsewhere on the board
SyncOut: U3.15 (2A3), U4.15 (2A3), U7.15 (2A3), U8.15 (2A3), U9.15 (2A3), U10.15 (2A3), U11.15 (2A3), U12.15 (2A3); also elsewhere on the board
YOutSwitched: U13.7 (2B2); also elsewhere on the board
YPbPrIsSelected: U6.8, U14.4 (~E1), U15.6 (E3)
YPbPrIsSelected0: R5.2, U15.15 (Y0)
YPbPrIsSelected1: R6.2, U15.14 (Y1)
YPbPrIsSelected2: R7.2, U15.13 (Y2)
YPbPrIsSelected3: R8.2, U15.12 (Y3)
YPbPrIsSelected4: R9.2, U15.11 (Y4)
YPbPrIsSelected5: R10.2, U15.10 (Y5)
YPbPrIsSelected6: R11.2, U15.9 (Y6)
YPbPrIsSelected7: R12.2, U15.7 (Y7)

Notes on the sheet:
inverting line decoder
rgb/ypbpr led logic
indicator leds
bus transceivers
Korean Hroparts Elec K3-1290S-E1
rgb/ypbpr switches
only one of these is active at any given time.

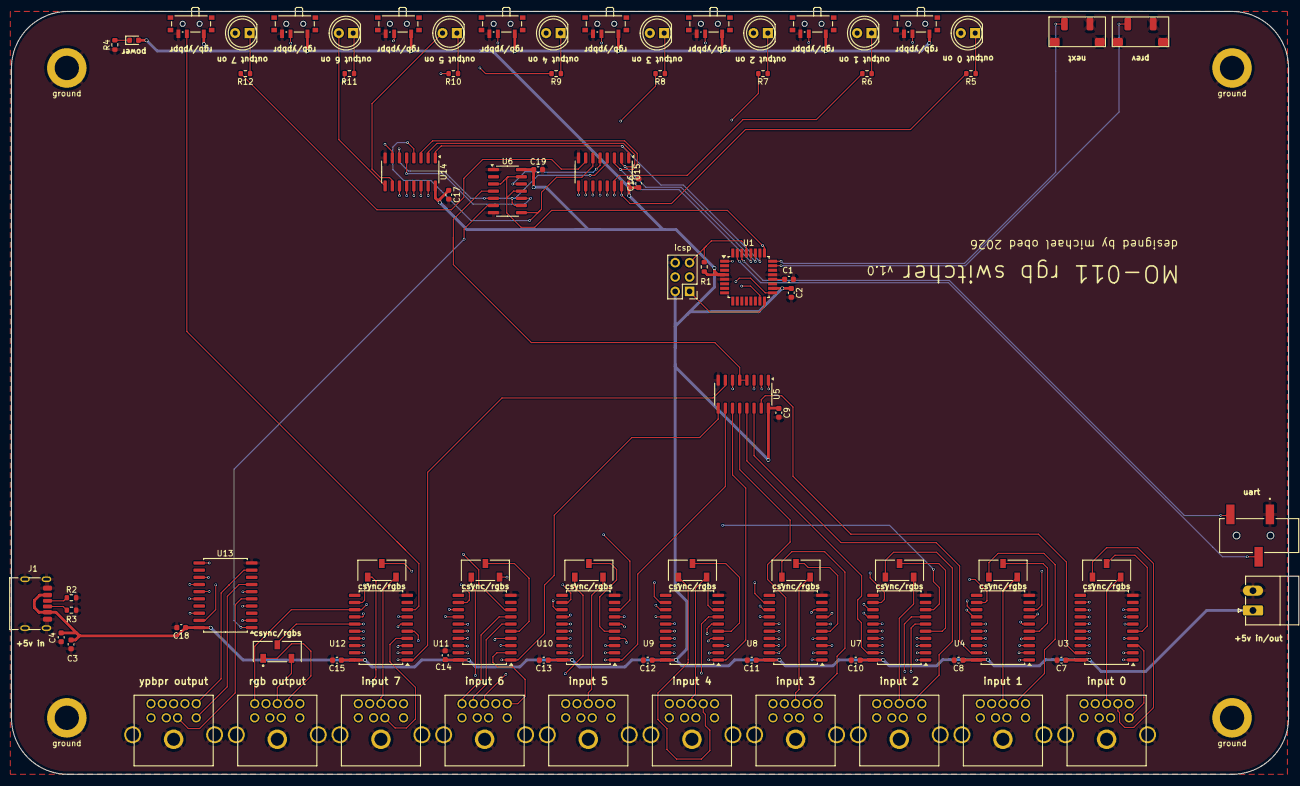
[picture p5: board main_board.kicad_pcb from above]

Board: 4 copper layers, 226.0 x 135.0 mm, 89 parts (0 on the bottom side), 142 nets.

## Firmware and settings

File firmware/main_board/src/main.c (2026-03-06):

//
//  main.c
//  main-board
//
//  Created by michaelobed on 03/01/2025.
//  
//  Copyright © 2025 Michael Obed.

#include "../../common/ctrl.h"
#include "io.h"
#include "mem.h"
#include "../../common/sys.h"
#include "../../common/uart.h"

int main(void)
{
    ctrlParams inputZero;

    IoInit();
    MemInit();
    UartInit();

    /* Select input 0 to avoid invalid state of front indicator LEDs. */
    inputZero.bytes[0] = '0';
    CtrlHandleCmd(Cmd_InputSwitch, &inputZero);

    while(TRUE)
    {
        UartHandler();
        IoButtonHandler();
    }
}

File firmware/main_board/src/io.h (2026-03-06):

//
//  io.h
//  main-board
//
//  Created by michaelobed on 03/01/2025.
//  
//  Copyright © 2025 Michael Obed.

#ifndef io_h
#define io_h

#include "../../common/sys.h"

#define PIN_SELEN                       PC2
#define PIN_SEL0                        PC3
#define PIN_SEL1                        PC4
#define PIN_SEL2                        PC5

#define PIN_LEDR                        PD6
#define PIN_LEDB                        PD3
#define PIN_LEDG                        PD5

#define PIN_BTNPREV                     PC0
#define PIN_BTNNEXT                     PC1

#define PIN_MOSI                        PB3
#define PIN_MISO                        PB4
#define PIN_SCK                         PB5
#define PIN_SS                          PB2

#define PIN_UARTRX                      PD0
#define PIN_UARTTX                      PD1

void IoButtonHandler(void);
void IoInit(void);
bool IoSelectInput(uint8_t input);

#endif

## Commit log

2025-01-24 Big ol' commit with all the stuff I did.
    [audio_biasing.kicad_sch, connectors.kicad_sch, led_switching.kicad_sch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]
2025-01-25 Stretch goals and JLCPCB-compatible BOM. Expanded hardware README with helpful links to some through hole components.
    [BOM.csv]
2025-01-25 Picture! 🤩
2025-01-25 I should probably mention cables.
2025-01-25 ...aaand I forgot the +5v out and I/O connectors from the BOM. D'oh! Updated alternative component list.
    [BOM.csv]
2025-02-07 #3: Added EEPROM "driver", LED EEPROM code and 4-byte sig to check whether data exists.
2025-02-07 #3: Change fuses to preserve EEPROM through erase.
    [main_board.kicad_sch]
2025-02-07 #3: Fuse change to guard against EEPROM corruption. Stay away from address 0x00!
    [main_board.kicad_sch]
2025-02-17 #1: Removed audio biasing circuitry as it's apparently unnecessary.
    [audio_biasing.kicad_sch, video_switching.kicad_sch]
2025-02-17 #1: Updated PCB layout and README.
2025-02-21 #1: No need for +2V5 rail if there's no audio biasing.
    [main_board.kicad_sch]
2025-03-13 Corrected UART connector name.
    [main_board.kicad_sch]
2025-03-25 Corrected odd trace kink in PCB artwork. KiCad v9 is required now.
    [led_switching.kicad_sch, main_board.kicad_sch, video_switching.kicad_sch]
2025-08-03 Fixed possible crash if OOB input index is received over UART (useful for turning everything off).
2026-02-13 #2: Add UART details to firmware README.
2026-02-13 #2: Hardware changes to accommodate new standby feature. Might as well commit symbol/footprint tables.
    [led_switching.kicad_sch, video_switching.kicad_sch]
2026-02-13 #2: Added 3D models for prev/next button footprint.
2026-03-06 #5: Removed LED-related things from main_board. Replaced power inlet with USB-C connector configured to accept 5V. Not sure what current consumption will be like though...
    [led_switching.kicad_sch, main_board.kicad_sch, video_switching.kicad_sch]
2026-03-06 #5: Removed LED-related things from main_board firmware.
2026-03-06 #5: Got the PCB layout into a relatively clean state before I play with the layout and size.
    [main_board.kicad_pcb, main_board.kicad_sch]
2026-03-16 #5: Honey, I shrunk the board! It's now 135x226mm and devoid of LED-related things.
    [main_board.kicad_pcb, video_switching.kicad_sch]
2026-03-16 #5: Fixed some 3D model and silkscreen things.
    [main_board.kicad_pcb]
2026-03-16 #5: Moved prev/next buttons closer to the edge for ease of use. Fixed issue with mounting hole positions. They are now consistently 10mm from their nearest edges.
    [main_board.kicad_pcb]
2026-03-16 #5: Fix missing C19. Minor artwork updates. Actually, why not let the +5v connector be in/out?
    [main_board.kicad_pcb, main_board.kicad_sch]
2026-03-16 #5: Properly handle unused NOT gate. Prune unused symbol/footprint libs.
    [main_board.kicad_pcb, main_board.kicad_sch, video_switching.kicad_sch]
2026-03-16 #5: Upversioned the board finally! Migrated BOM format to use "KiCAD JLCPCB tools" plugin. Updated hardware README.md.
    [BOM.csv, main_board.kicad_pcb, main_board.kicad_sch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]
2026-03-16 #5: Started LED board project. More README.md updates. Move MTS-102 footprint to LED board.
    [led_board.kicad_pcb, led_board.kicad_sch, main_board.kicad_pcb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]
2026-03-16 #5: Fixed dumb mistake I made where I got rid of the power LED!
    [main_board.kicad_pcb, main_board.kicad_sch]
2026-03-16 #5: Fixed botched dimensions again...it's only by 0.1mm in the x direction and I can't be bothered redoing the render a 3rd time.
    [main_board.kicad_pcb]
2026-03-17 #5: We have a completed LED board! 🎉
    [led_board.kicad_pcb, led_board.kicad_sch]
2026-03-17 #5: Text spacing pedantry. LED board now gets its own README.md, so other READMEs needed updating.
    [main_board.kicad_pcb]
2026-03-17 #5: Actually add LED board BOM.
2026-03-17 #5: I forgot adding the BOM has consequences on the PCB project itself. Corrected similar things on main board.
    [led_board.kicad_pcb, main_board.kicad_pcb]
